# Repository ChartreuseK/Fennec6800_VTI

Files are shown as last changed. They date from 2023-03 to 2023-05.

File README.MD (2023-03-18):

# Fennec 6800 Video Terminal Interface (VTI) Expansion

This expansion board is designed for use with the [Fennec 6800 SBC](https://github.com/ChartreuseK/Fennec6800). It provides a 64 column by 16 line video display over composite ("NTSC") video or a CGA compatible monitor. In addition to the video display it also provides for a parallel ASCII keyboard interface on either a DIP14 IDC header, or over a DA-15 connector. Combined with an Option ROM that hooks into the Fennec 6800's BIOS, this provides for a full video terminal interface for the Fennec, negating the need for an external terminal on the first serial port. 

Connection to the Fennec is accomplished by a 1:1 wired 40 pin IDC cable between the two, multiple expansions may be attached to the bus using such a straight through wired cable. A common 40 pin IDE cable with no key plug may be used for this purpose, however an 80 pin IDE cable should never be used as they internally connect many pins to ground.

Through the use of a 6845 VDP, and socketed crystal, the interface can be reprogrammed to a number of different possible graphics modes. With 2kB of VRAM provided by a 6116/4016 SRAM, the interface can support up to 80x25 text mode when combined with an appropriate dot clock and an 8x8 font. Using a larger font ROM than the 2716 is also possible, with up to 32kB of font ROM being possible, allowing for extra tall and detailed characters. However due to non-interlaced composite video's vertical line count this will result in significantly less lines displayed. 

The ASCII keyboard interface is provided via a 6820/6821/6521 PIA, giving a full 8-bit ASCII interface with strobe to the keyboard. The second 8-bit port of the PIA is not used and is provided on a pin header for the user to experiment with and control. In addition a small prototyping area is available on the right hand side of the card to be used for such experiments.

Only 5v is provided to the keyboard, so vintage keyboards requiring extra voltages such as -12v will need to be supplied that externally.

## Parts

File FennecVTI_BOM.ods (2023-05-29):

Reference(s) | Qty | Part | Digikey Part # | Alternative Digikey Part # (ICs are HCT instead of LS)
C1 | 1 | 470uF 16v Electrolytic 3.5mm pitch 8mm diameter | P19636CT-ND | 493-14210-1-ND
C2 | 1 | 47uF 16v Electrolytic 2mm pitch 5mm diameter | P11196-ND | 493-1775-ND
C3, C4, C5, C6, C7, C8, C9, C10, C11, C12, C13, C14, C15, C16, C17, C18, C19 | 17 | 0.1uF 50v Ceramic Capacitor, .1” pin pitch | 399-14036-1-ND
D1 | 1 | T1-3/4 (5mm) low-brightness red LED | 160-1707-ND
D2 | 1 | 1N4148 DO-3 diode | 1N4148FS-ND
J1 | 1 | 2x20 0.1” male pin header | 10129381-940002BLF-ND | S2011EC-40-ND
J2 | 1 | 2x6 0.1” male pin header | 2057-PH2-12-UA-ND | S2011EC-40-ND
J3 | 1 | Right-Angle RCA connector | 2092-KLPX-0848A-2-Y-ND | PJRAN1X1U04X-ND
J4 | 1 | DE9 Right-Angle Female | AE10921-ND
J5 | 1 | DA15 Right-Angle Female | AE10976-ND
J7 | 1 | 1x14 0.1” male pin header | 2057-PH1-14-UA-ND | S1011EC-40-ND
JP1 | 1 | 1x2 0.1” male pin header | 2057-PH1-02-UA-ND | S1011EC-40-ND
JP2 | 1 | 1x3 0.1” male pin header | 2057-PH1-03-UA-ND | S1011EC-40-ND
JP3 | 1 | 1x2 0.1” male pin header | 2057-PH1-02-UA-ND | S1011EC-40-ND
JP4 | 1 | 1x2 0.1” male pin header | 2057-PH1-02-UA-ND | S1011EC-40-ND
Q1 | 1 | 2N3906-AP TO-92 package PNP | 2N3906FS-ND
R1 | 1 | 4.7k ohm 1/4 5% Carbon Film Resistor | CF14JT4K70CT-ND
R2, R4 | 2 | 220 ohm 1/4 5% Carbon Film Resistor | CF14JT220RCT-ND
R3 | 1 | 10k ohm 1/4 5% Carbon Film Resistor | CF14JT10K0CT-ND
R5 | 1 | 470 ohm 1/4 5% Carbon Film Resistor | CF14JT470RCT-ND
U1 | 1 | 74LS191 DIP | 296-14886-5-ND | 296-2141-5-ND
U2 | 1 | MC6845 | Vintage, eBay
U3 | 1 | 74LS86 DIP | 296-1669-5-ND | 296-2133-5-ND
U4 | 1 | 74LS30 DIP | 296-3693-5-ND | 296-2111-5-ND
U5 | 1 | 6116 SRAM | Vintage, eBay
U6 | 1 | 74LS245 DIP | 296-1655-5-ND | 296-2105-5-ND
U7, U12 | 2 | 2716 EPROM or 28C16 EEPROM | Vintage, eBay
U8 | 1 | 74LS74 DIP | 296-1668-5-ND | 296-1605-5-ND
U9 | 1 | 74LS139 DIP | 296-1640-5-ND | 296-8390-5-ND
U10 | 1 | 74LS574 DIP | 296-1504-5-ND | 296-2129-5-ND
U11, U13, U15 | 3 | 74LS157 | 296-1645-5-ND | 296-2095-5-ND
U14 | 1 | 74LS166 | 296-3662-5-ND | 296-2099-5-ND
U16 | 1 | MC6820/6821 or MOS 6520/6521/65C21 | Vintage, eBay | (Mouser) 955-W65C21S6TPG-14
U70, U120 | 2 | Optional 2764/27128/27256/27512/28C64 subs. For U7/12 | Vintage, eBay | AT28C64B-15PU-ND
X1 | 1 | ACO-12MHz full-can oscillator | 535-9205-5-ND | 535-9169-5-ND
Sockets
U3, U4, U8, J6 | 4 | DIP-14 (0.3”) socket | 2057-ICS-314-T-ND
U1, U9, U14, U11, U13, U15 | 6 | DIP-16 (0.3”) socket | AE9992-ND
U6, U10 | 2 | DIP-20 (0.3”) socket | AE9998-ND
U2, U16 | 2 | DIP-40 (0.6”) socket | ED3033-ND
U5, U7, U12 | 3 | DIP-24 (0.6”) socket | 1175-2554-ND
U70, U120 | 2 | DIP-28 (0.6”) socket substitute for U7,U12 | 2057-ICS-628-T-ND
X1 Socket | 1 | DIP-14 (0.3”) crystal socket. 4 pins fitted | ED90428-ND

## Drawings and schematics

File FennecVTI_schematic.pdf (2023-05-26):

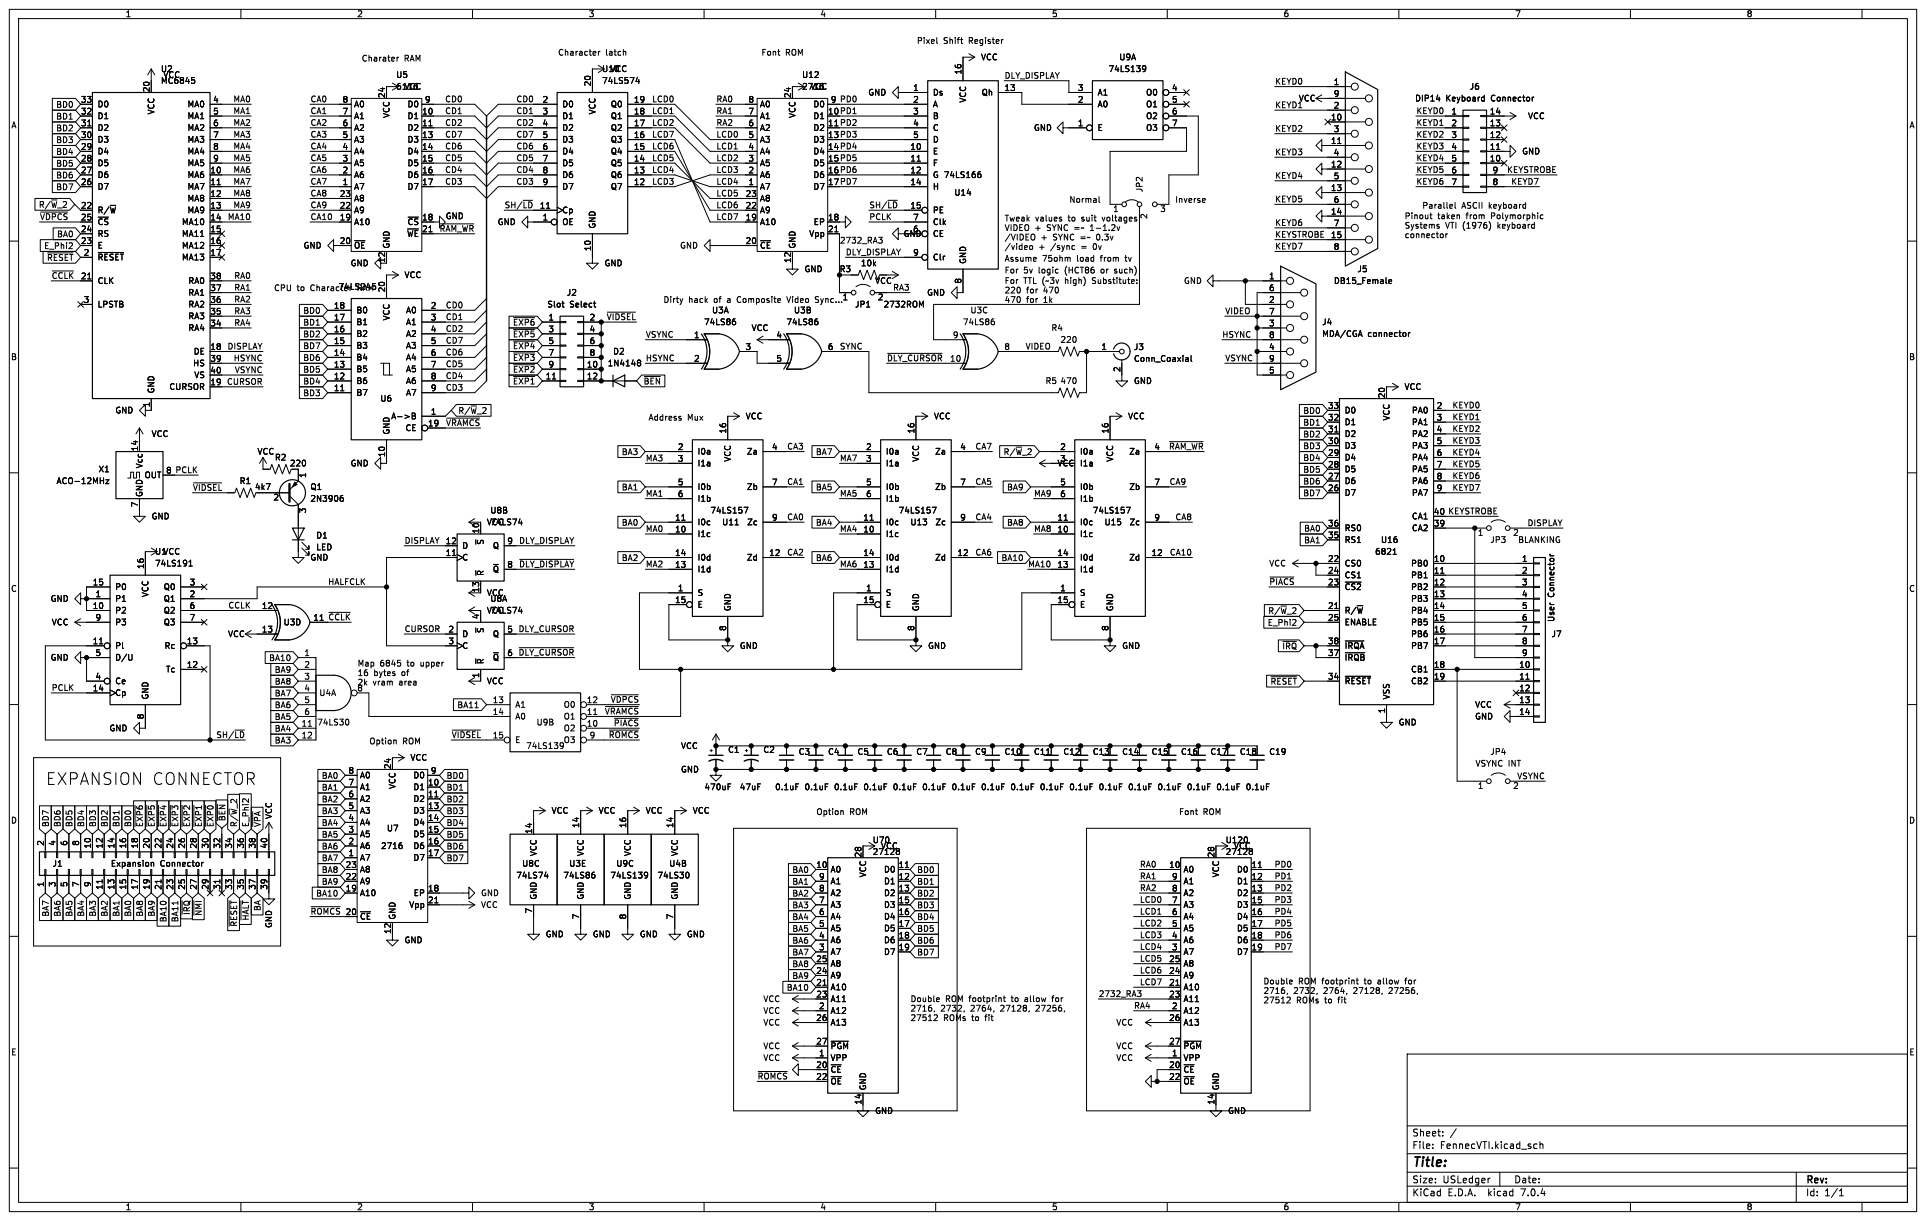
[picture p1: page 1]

1 MA6 10 MA7 11 MA8 12 MA9 13 MA10 14 MA11 15 MA12 16 MA13 17 DE 18 CURSOR 19 ~{RESET} 2 VCC 20 CLK 21 R/~{W} 22 E

Id: 1/1 Title: File: FennecVTI.kicad_sch Sheet: / VCC 14 GND

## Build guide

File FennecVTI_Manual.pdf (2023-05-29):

# Fennec 6800 Video Terminal Interface

## A Motorola 6845 Based Composite Video and ASCII Keyboard Terminal Interface for the Fennec 6800

## Designed By: Chartreuse

2023

Manual Revision 0.1 – May 2023 | 1 | Fennec 6800 VTI User Manual

Dedicated to the Retro Dreams Discord Server for all the help and discussions over the years.

## Introduction

The Fennec 6800 VTI is a simple composite video based terminal interface with parallel ascii keyboard input for the Fennec 6800 single board computer. Video timing is generated by a Motorola 6845 CRT controller, allowing for flexible timings and customization by the end user. 2kB of display memory is provided as well as a 2kB to 8kB font ROM (2716/2732/2764) allowing for an ASCII text display, and optionally pseudo graphics with an appropriate ROM. Input is handled by a parallel ASCII keyboard connection on either a DA-15 connector or a DIP-14 socket. Eight data inputs and a strobe line from the keyboard are passed to a 6820/6821/6520/6521 PIA chip for handling of the keyboard. An option ROM on the board hooks into the primary monitor ROM and redirects the primary I/O from the first serial port to the VTI interface instead.

## Specifications

- MC6845 CRT Controller (CRTC) for flexible display timing and control
- 2kB of video character memory (6116 SRAM)
- 2-8kB Font ROM allowing for a variety of font heights.
- Option ROM provides a local console for the Fennec, negating need for an external terminal
- DA-15 or DIP-14 parallel ASCII keyboard interface provided through 6820/6821/6520/6521 PIA
- Prototyping area on PCB for simple expansions and projects.
- Second un-used port on PIA broken out to headers for prototyping and interfacing.
- Jumperable inverse video allows for both white on black and black on white.
- RCA composite video output. (“NTSC” timing by default)
- DE-9 TTL Video Output (monochrome CGA by default)
- 12MHz dot clock.
- 64x24 Text Display with default dot clock, controllable with CRTC registers.
- Beautiful blue PCB with exposed traces for a refined look.
- Compact Board design, only 8.6×5.2 inches!

The Fennec VTI provides a flexible platform for text-based video generation on the Fennec as well as other systems with a similar bus interface providing a ~4kB memory window for interfacing. The low 2kB is directly mapped to the video memory, with the upper 16 bytes mapping to the 6845 registers. The upper 2kB is mapped to the option rom, with the upper 16 bytes mapping to the PIA registers.

The parallel ASCII keyboard interface is provided on both a DA-15 interface along with a DIP-14 header. The interface consists of 8 data lines, 1 strobe line, and 5v power and ground. Some vintage keyboards may require different voltages in which case an external adapter will be required. The keyboard interfaces directly to the PIA interface, with the data lines going to the A port, and the strobe line to CA1. Due to the flexibility of the PIA this allows the polarity of the strobe to be configured in software, as well as allowing for interrupt driven capabilities on the input in addition to polling.

The PIA also provides a 14 pin prototyping header with the B data port, as well as CA2, CB1, CB2, 5v and ground. This allows for quick and easy prototyping of small circuits to be controlled directly by the

Manual Revision 0.1 – May 2023 | 2 | Fennec 6800 VTI User Manual

Fennec computer. Coupled with the onboard prototyping area, small circuits may be built up semi-permanently into the computer itself.
Two jumpers are also provided which connect VSYNC and BLANK to CB1 and CA2 respectively, allowing for their status to be either queried by the program, or used as an interrupt source. These signals can be used for either simple timing with the VSYNC pin as a 60/50Hz interrupt source, or for advanced CRTC tricks such as only writing to display memory during BLANK to provide snow free operation.
Manual Revision 0.1 – May 2023 | 3 | Fennec 6800 VTI User Manual

## Design Goals

The VTI was designed to give the Fennec it’s own built in I/O system. I find that a computer doesn’t really feel complete by itself without a way of hooking up a display and keyboard directly to it; more-so in terms of homebrew machines where serial console based systems are a dime-a-dozen. The VTI board is intended to fill this gap by providing both a composite video text terminal as well as a keyboard interface. Part of this goal was also in demystifying the 6845 CRTC for myself and learning to interface one to a microprocessor. The VTI originally started as a breadboard project to just get a video circuit working with an interface to the processor. The Fennec’s simple bus allowed for a quick and easy setup and interfacing for the design.

One consideration when using the 6845 and similar CRTC based circuits is how to handle the situation where both the video circuit and the microprocessor both want to access the display memory. There are many approaches here such as synchronizing the processors clock rate to that of the video circuit to allow for seamless access; accessing the video memory only during blanking intervals where the video circuit is not using/caring about the video on screen; adding wait states to the processor till the video controller is no longer accessing the memory; or the simplest option that the CPU always has priority. The simplest option is what I decided to go with in this case.

Now the upside to this CPU always wins option is simplicity, all we need to control the VRAM access is a set of multiplexer chips and data bus buffers. The multiplexer is on the address lines to the VRAM, and control is simply controlled by the CPU selecting the VRAM memory space. The big downside to this approach is what happens during these conflicts? Well “snow” is what happens. Snow is the term used for the appearance of small glitches on the display when the CPU access the VRAM while the CRTC is also trying to display pixel data. Instead of the intended character data, the video circuit instead picks up the state of the data bus from the CPU and displays that instead. This results in an 8x1 pixel section of the video containing garbage for a single frame for each VRAM access. This type of access was fairly common on some early video cards, most notably the IBM CGA card when in 80 column mode. It is an unwanted side effect, but not terribly distracting when VRAM is only updated periodically. Since the VTI card is intended primarily as a text-terminal, this distraction would be minimal and is made up for in the design simplicity.

One thing that can be done in the future with this simple interface is to convert it to the second type. That is only doing VRAM access during blanking. When I created the PCB version of the VTI I thought to add a jumper to allow for the BLANK signal to be hooked up to the PIA providing the keyboard access. Using this the ROM can be upgraded to wait until BLANK is asserted before doing any VRAM accesses. This would slow down the characters per second that the display is capable of but would completely eliminate all snow from the display with only a software and jumper upgrade.

The keyboard interface was a later addition to the project and not present on the original prototyped breadboard circuit. I decided to go with a parallel ASCII keyboard interface to fit with the late 70s type feel and goal of the Fennec, as such keyboards were ubiquitous in systems of the era. In fact, the pinout used on the DIP-14 keyboard connector is taken from a 1976 Polymorphic Systems VTI card for S100 systems that I have in my collection; the card also being one of my primary inspirations for the project. While a PS/2 keyboard interface would be more convenient for users it broke the immersion of the system too much. To compensate though, and because I do not own any parallel ASCII keyboards

Manual Revision 0.1 – May 2023 | 4 | Fennec 6800 VTI User Manual

personally, I did make a side project PCB based off of https://www.n4vlf.net/ps2.html to convert a PS/2 keyboard to the parallel ASCII required.
For interfacing with the keyboard, while I could simply use an 8-bit latch such as the 74LS574 or a period parallel interface like the 8212. I decided to stick with Motorola parts to fit the design of the system. To this end I selected the 6820/6821 PIA chip. This chip provides for two 8-bit general purpose I/O ports along with 4 additional I/O pins that can be configured to fire interrupts among other uses. With this chip I can simply hook up the 8 data lines from the keyboard to one of the I/O ports, and hook up the strobe into to one of those additional I/O lines. Then the setup can be used in either a polled or interrupt driven mode to get the characters from the keyboard. Another benefit of using PIA chip is the ability of the strobe polarity to be chosen and edited in software to adjust for different keyboards, along with translating key codes if needed.

As the PIA provides for two I/O ports and I did not require the second port for the terminal interface, I brought out the port to a pin header on the PCB, allowing for it to be used by the end-user for interfacing with whatever devices and projects they see fit. As well with the extra space on the board a 0.1” pad per hole prototyping area was also left for this purpose.

While not implemented on the board a feature that I believe I should have added was for jumpers to hook up the high address lines on 2732 and 2764 EPROMS to pins on the PIA instead of to additional row address lines on the CRTC. This would allow for software to change between different fonts or even pseudo-graphics on the font rom for display.

Manual Revision 0.1 – May 2023 | 5 | Fennec 6800 VTI User Manual

## Theory of Operation

Video Display
The heart of the video timing is the Motorola 6845 CRTC. This integrated circuit is by and large a glorified counter chip, capable of counting up characters in the horizontal direction, and characters made up of a number of rows in the vertical direction. With this counting it divides a line into a blanking region, a sync pulse in the middle of that blanking region, and a visible region. Likewise in the vertical direction it has a blanking region, a vertical sync region in the middle of the blanking, and a visible region. With just these attributes we get a vertical sync signal, a horizontal sync signal, and a blanking signal. These alone are enough to get a display to synchronize but we still need more in order to display information on the screen. That’s where the address generator comes into play. For each character cell on the screen the CRTC generates an address for us, starting from the top left of the screen, working it’s way to the right, then going down one cell and continuing. The power of the CRTC here is that it’s able to do these for arbitrary row widths, as opposed to discrete circuits that are typically limited to powers of 2 for simplicity sake. As characters on the display are normally
composed of a number of rows, for example 8, the CRTC repeats the character address for that many rows down the screen. To differentiate the rows and move to different rows of the font the CRTC also provides a row address output. This output simply counts the current scanline within the character row. Now the 6845 CRTC is more powerful than this and offers some additional features, but this is enough to explain the heart and building blocks of our video generation circuit.
We’ll start with the visible portion of the screen. For any given time in the visible area the CRTC is outputting a character address on the MA0-MA13 bus. For the Fennec VTI the display memory is 2kB provided by a 6116 SRAM chip thus we need just 11 address lines MA0 to MA10, the upper 3 address lines are left disconnected. These address lines are connected to the SRAM chip through a multiplexer which we will discuss later, but for now just imagine them directly connected to the SRAM chip.
The Fennec VTI video circuit is designed as character based display dividing the screen up into a region of 64x24 characters, and the CRTC chip is designed especially to make this kind of setup easy. The character addresses will be appropriately repeated on subsequent scan-lines with the row address incremented until the number of rows in a character is reached. What all this means for us is that in the SRAM one byte corresponds uniquely to each character cell on the screen in row-column order. The output of the RAM is then latched into a 74LS574 octal d-flip-flop. This flip flop acts to keep the output stable to the font ROM. While likely strictly not needed it should help to slightly reduce the amount of snow on the screen. From this latch the value is then connected to the A3-A10 address inputs to the 2716 font ROM.
At the font ROM we need to combine the the character value we get from the RAM with the row address from the CRTC to select the line in the font that corresponds to the current line on the display. The VTI is primarily designed for use with an 8x8 font, meaning we need 8 rows or 3 bits to uniquely select a row of the font. This row address on RA0-2 from the CRTC is directly connected to the A0-A2 inputs on the font ROM. With a 2716 EPROM this combination of 8+3 bits fully utilizes the ROM. If a
Manual Revision 0.1 – May 2023 | 6 | Fennec 6800 VTI User Manual

larger ROM such as a 2732 or 2764 are used then more rows can be added to the font. To allow the use of this a jumper is provided to connect RA3 to A11 on a 2732. And if the 2764 footprint is used RA4 will also be connected to A12. Keep in mind that on a standard NTSC television we only have 262 scanlines to work with without going into interlaced mode, with only around 240 visible at most, which will limit the useful font heights without compromising with fewer rows of text.
The output of the font ROM is then latched into a 74LS166 8-bit parallel to serial shift register. This shift register is then clocked at the dot clock (12MHz) to output the pixel data serially to the display. Now the complex part here is latching the pixel data at the right point. If we tried to do it right away as the CRTC changes character address we’d be latching the previous character value’s data from the ROM. This is because every step of the circuit has its own delay. The RAM has an access time on the order of 100ns (though in my build my D4016 SRAM is a fast 50ns model). The ROM has an access time on the order of 150ns for the slowest ROMs. And the latch between them is also clocked at a certain point, but also has a small delay on the order of 10ns or so. Now ~300ns doesn’t sound like a lot of time, but at television frequencies and with a dot clock of 12MHz, that 300ns corresponds to 3.6 pixel times. To account for variance and provide a stable synchronous setup I decided that the latch between the RAM and ROM will latch at the same time as the shift register will latch the output of the font ROM. This setup means that there will be a 1 character delay or pipeline from the address changing and the shift register getting that character data. This delay we will account for in the software timing and adjusting the blanking interval, but will provide a rock solid setup without having to worry about variable asynchronous delays.
To time this latch we need to go to the dot clock and how the CRTC is clocked. The 6845 CRTC does not take a dot clock as input but takes in a character clock; remember the CRTC is a character display device. Since our characters are 8 pixels wide (corresponding conveniently to one byte worth of pixels) we need to divide our dot clock by 8 to get our character clock. A 74LS191 4-bit universal bi-directional pre-loadable counter is used for this purpose. To generate the dot clock we make use of the 3

rd bit of the counter to act as a divide by 8 of the dot clock. For timing reasons we will get back to, this character clock is actually inverted before being input into the CRTC.
The counter is pre-loaded with the value 8 (1000 in binary), and is reset to this value every time it overflows. We do this as we only want to use the low 3 bits of the counter, but we also want to make use of the single clock pulse long carry output that the counter provides. This output is normally used for creating a ripple-carry system of multiple counter chips, but we wish to use it to act as our latch signal for the flip flop and shift register. This output is also hooked back up to the parallel load input which will reset the counter to 8 on the next clock cycle, effectively turning the counter into a 3-bit counter. The output is active low and in the schematic is called the SH/LD signal. When high the shift register will be shifting out the data currently in it to the display, and for the single dot clock that it is low the shift register will latch in the new data from the font ROM.
...To be completed...
Manual Revision 0.1 – May 2023 | 7 | Fennec 6800 VTI User Manual

## Assembly

Assembly is rather straight forward but should be accompanied by the schematic or bill of materials to know where to place the various resistors. I’ve corrected this for my future boards, but this board only has the reference designators and not the component values marked.
Like other throughole kits I would recommend starting from the shortest components to the tallest components, and I would personally recommend sockets for the ICs, especially the vintage ones, though they are not required. My personal assembly order would be to do the IC sockets first, even if they’re taller than the resistors, but either approach has it’s merits. For the tantalum capacitors to the side of the RAM, and the two electrolytic capacitors, make sure to get their polarity correct. Both have their positive side marked on the board, for tantalum capacitors their positive lead is normally marked with a + sign or stripe on the capacitor, and for electrolytics their negative side is normally marked with a stripe. If cost is a factor, feel free to omit some of the tantalum capacitors as the number is likely overkill as I miscalculated the current dram of the SRAM chips (mainly due to only a single pair being active at any one time).
Manual Revision 0.1 – May 2023 | 8 | Fennec 6800 VTI User Manual

## Assembly

Assembly is rather straight forward but should be accompanied by the schematic or bill of materials to be safe. All component and IC values are marked on the board itself to facilitate painless assembly. For the dual-size ROM sockets align the socket to the appropriate pin 1 mark depending if using a 28 pin socket for 2764 EPROMs or 24 pin socket for 2716 EPROMs. The inner marking is for 24 pin ROMs. If installing a 24 pin ROM into a 28 pin socket, take care to seat it all the way to the right, leaving the 4 extra socket holes on the pin 1 side.
Like other throughole kits I would recommend starting from the shortest components to the tallest components, and I would personally recommend sockets for the ICs, especially the vintage ones, though they are not required. My personal assembly order would be to do the IC sockets first, even if they’re taller than the resistors, but either approach has it’s merits. For the two electrolytic capacitors, make sure to get their polarity correct. Both have their positive side marked on the board; for electrolytics their negative side is normally marked with a stripe.
If you are using a 74LS86 IC then use the resistor values printed in the footprints, 220 and 470 for R4 and R5 respectively. If you are substituting in a 74HCT86 then use the values written above, substituting the 220 resistor for a 470, and the 470 resistor for a 1k.
Unless you’ve modified the software to work in another slot, place a jumper shorting cap on the left-most (pin 1) pair of pins on J2 to select the EXP6 slot for the board.
As well, place a shorting jumper on pins 1-2 (right most) of J2, connecting the side labelled NORM to the center pin. This configuration will give white text on a black background, use the other position for black text on a white background if desired.
Program the Option ROM with the latest version of vtirom.bin This ROM will provide the routines for the display as well as hook into the main ROM to provide the main monitor console over the VTI instead of the first serial port.
Program the Font ROM with an 8x8 bitmap font of your choice, I do not currently provide one but I recommend the IBM CGA font ROM or similar as a good base choice. The font is stored as 1 byte per row, and top to bottom row order for each ASCII character in order, with the high bit of each byte being the left most pixel of the character.

Required Bodges (REV.0 ONLY)
I highly recommend upgrading to a rev 1 board if possible however a rev 0 board can be brought up to a working state with a few bodges. For wiring I recommend 26 or 30 AWG wire wrap wire (0.4 to 0.25mm wire) for doing the neatest bodges. Wire-wrap wire has thin insulation of Kynar (PVDF) or sometimes Teflon (PTFE) and is silver plated copper wire, and is ideal for bodges like these.
Manual Revision 0.1 – May 2023 | 9 | Fennec 6800 VTI User Manual

Inverting 74LS157 Select Line
Due to a mix-up in the wiring the select line for the 74LS157 mutliplexers is the opposite polarity to expected. This is fixed in rev 1, but in rev 0 boards requires the addition of a 74LS04 hex-inverter to the prototyping area. Install a 74LS04 inverter into the bottom left most area of the prototyping area of the card. Hook up VCC to pin 14, and GND to pin 7. Find the trace that runs under all 3 74LS157 multiplexers, and is between the power and ground lines running horizontally. Cut this trace to the right (if looking from the bottom) of all 3 multiplexers. This should be near where the two power traces end. Solder a wire from the right of this cut to pin 1 on the added inverter. And solder a wire from pin 2 of the inverter to anywhere on this trace to the left of the cut.

Inverted 74LS245 R/W Line
We will be using the same 74LS04 inverted added by the bodge above, so complete that first. On the top side of the board locate U6, the 74LS245. Cut the left most trace below in to the right of the ceramic capacitor, this should be the small trace that runs under the ROM below the IC. Flip the board over. Run a wire from pin 1 of the 74LS245 to pin 4 of the added inverter. Run a wire from pin 3 of the inverter to pin 34 of the expansion connector (if looking from the back with the dsub connectors on the right this is the 4th pin in on the top row).

INV Display Mixup
Directly above the 3 pin header for INV and NOR display. Cut the trace going to the left-most (INV) position of the header below the IC. Flip the board over. Solder a short wire between the INV pin and pin 5 of the 74LS139 U9.
Flip the board right side up again. To the right of the NOR text, cut the pair of traces leading downward before the via. This should be approximately level with the R in NOR. Using a pair of short bodge wires, cross these traces from one side to the other. That is, on the left trace, above the cut run a wire to the right trace below the cut, and for the right trace, above the cut run a wire to the left trace below the cut.

Flipped Composite Jack
The composite video RCA jack has been wired with the signal on the outer shell, and ground on the center pin. You can chose to make an adapter cable which flips this, or perform the following bodges to repair it correctly. On the top side of the board, cut the thick ground trace below the RCA jack between the jack and the DE-9 connector. On the top side of the RCA jack cut both of the thick traces leading from the jack below resistor R5. Flip the board over. Run a wire from the large ground trace below the jack to the single pin on the board edge side of the RCA jack. Cut the trace from the pin 1 side of the ceramic capacitor to the left of the RCA jack leading to the two pin side of the RCA jack. Run a wire from the same ground as before to the pin 1 side of that ceramic capacitor. Run another wire from that capacitor up to the ground lead of capacitor C2. Finally run a wire from the two pin side of the RCA jack (tip) to the board edge side of resistor R5 (directly above the RCA jack).
Manual Revision 0.1 – May 2023 | 10 | Fennec 6800 VTI User Manual

Manual Revision 0.1 – May 2023 | 11 | Fennec 6800 VTI User Manual

## Bill of Materials

Ceramic Capacitors
- 17x 0.1uF 50v X7R with 0.1” (2.54mm) lead spacing Aluminum Electrolytic Capacitors
- 1x 470uF 16v with 3.5mm lead spacing, max diameter 10mm.
- 1x 47uF 16v with 2mm lead spacing, 5mm diameter Sockets (Optional)
- 4x DIP-14
- 6x DIP -16
- 1x DIP-14 *or* DIP-8 crystal socket (only 4 corner pins fitted) for main oscillator
- 2x DIP-20 (0.3” wide)
- 1x DIP-24 (0.6” wide) socket for 6116 SRAM
- 2x DIP-24 (0.6” wide) sockets for ROMs if using 2716/2732
- 2x DIP-28 (0.6” wide) sockets for ROMs if using 2764
- 2x DIP-40 (0.6” wide)
Connectors
- D-sub DA-15 Right-Angle Female with 7.70mm pin edge offset, 9.12mm mounting hole offset
- D-sub DE-9 Right-Angle Female with 7.70mm pin edge offset, 9.12mm mounting hole offset
- RCA Female Jack, Right-Angle
- 1x 2x20 0.1” male pin header
- 1x 2x6 0.1” male pin header
- 3x 1x2 0.1” male pin header
- 1x 1x14 0.1” male pin header
- 1x 1x3 0.1” male pin header
- (I recommend getting 1x40 and 2x40 breakaway headers and cutting them down)
- 2x 0.1” shorting jumper (+1 if using 2732 or larger font ROM)
Resistors
- 1x 10k 1/4W Carbon Film
Manual Revision 0.1 – May 2023 | 12 | Fennec 6800 VTI User Manual

- 2x 220 1/4W Carbon Film
- 1x 4.7k 1/4W Carbon Film
- 1x 470 1/4W Carbon Film
- If using a 74HCT86 or similar then add 1x 1k 1/4W Carbon Film, and leave out one of the 220 ohm resistors
Diodes
- 1x 1n4148 or similar small signal high speed diode
- 1x 5mm LED. Colour of your own preferenceor but a deep red low brightness LED recommended.
Transistors
- 1x 2n3906 PNP Transistor in TO-92 package with staggered center pin Integrated Circuits
- 1x Motorola MC6845 CRTC, any speed grade should be fine
- 1x 12MHz DIP-14 (full can) or DIP-8 (half can) oscillator
- 1x Motorola MC6820/6821 or MOS 6520/6521 or compatible PIA
- 2x 2716 EPROM or 28C16 EEPROM or compatible. 2764 may also be used (larger will work but only first 2kB of option ROM and 8kB of font ROM usable)
- 1x 6116 or compatible (eg. D4016) 2k x 8 SRAM
- 1x 74LS86 quad XOR
- 1x 74LS166 8-bit parallel to serial shift register
- 1x 74LS139 dual 2-4 selector
- 1x 74LS245 octal bus transciever
- 1x 74LS574 octal d-flip-flop
- 1x 74LS30 8 input NAND gate
- 3x 74LS157 2:1 multiplexers
- 1x 74LS191 4-bit universal counter
- 1x 74LS74 dual D-flip-flop
Manual Revision 0.1 – May 2023 | 13 | Fennec 6800 VTI User Manual

## BOM Table

Manual Revision 0.1 – May 2023 | 14 | Fennec 6800 VTI User Manual

## IC Layout Diagram

U5 6116

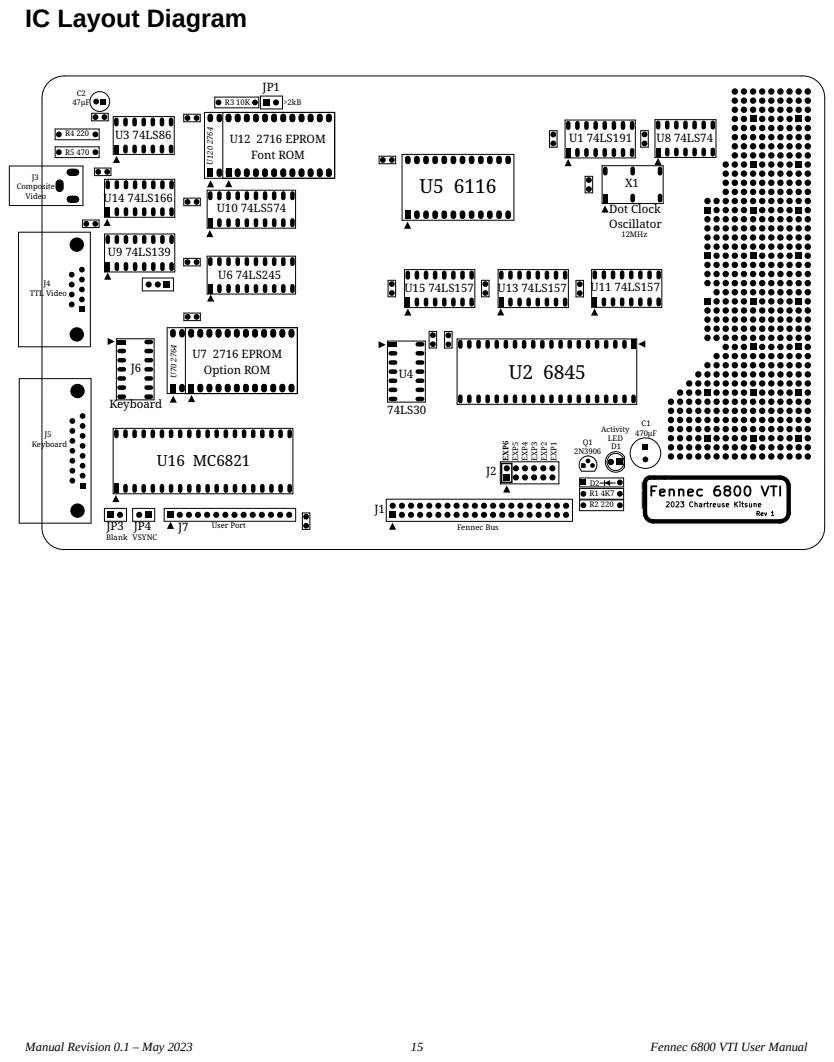
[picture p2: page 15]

## Schematic

For the most up to date schematics, check out the KiCAD project in the repository. These schematics are up to date as of REV 1 or REV 0 with bodges applied.

Manual Revision 0.1 – May 2023 | 16 | Fennec 6800 VTI User Manual

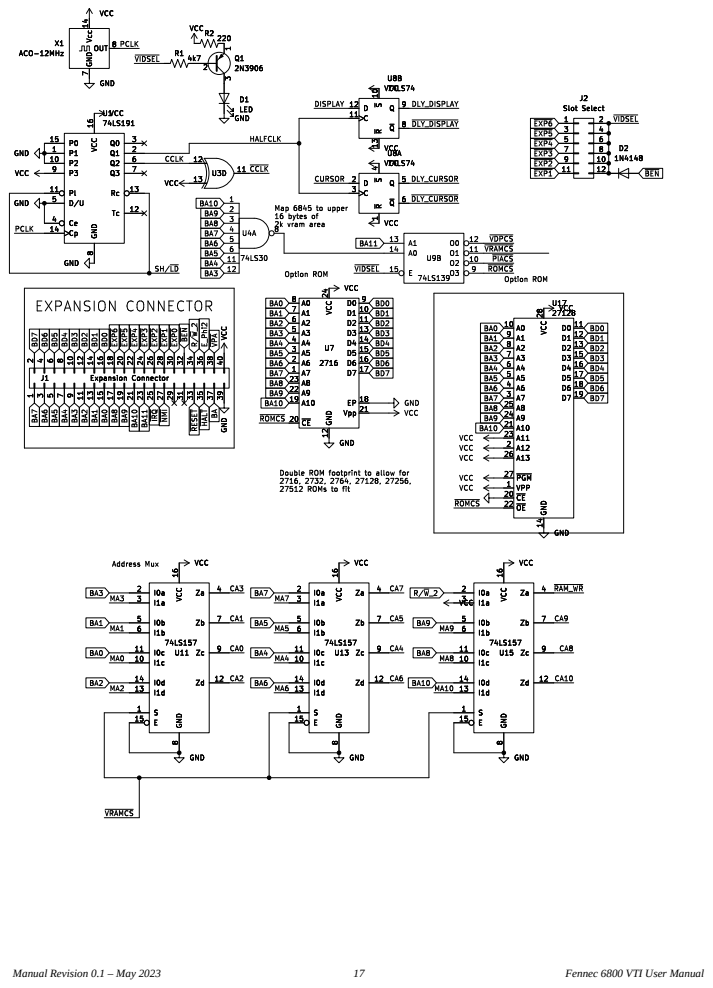
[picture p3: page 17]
Manual Revision 0.1 – May 2023; Fennec 6800 VTI User Manual

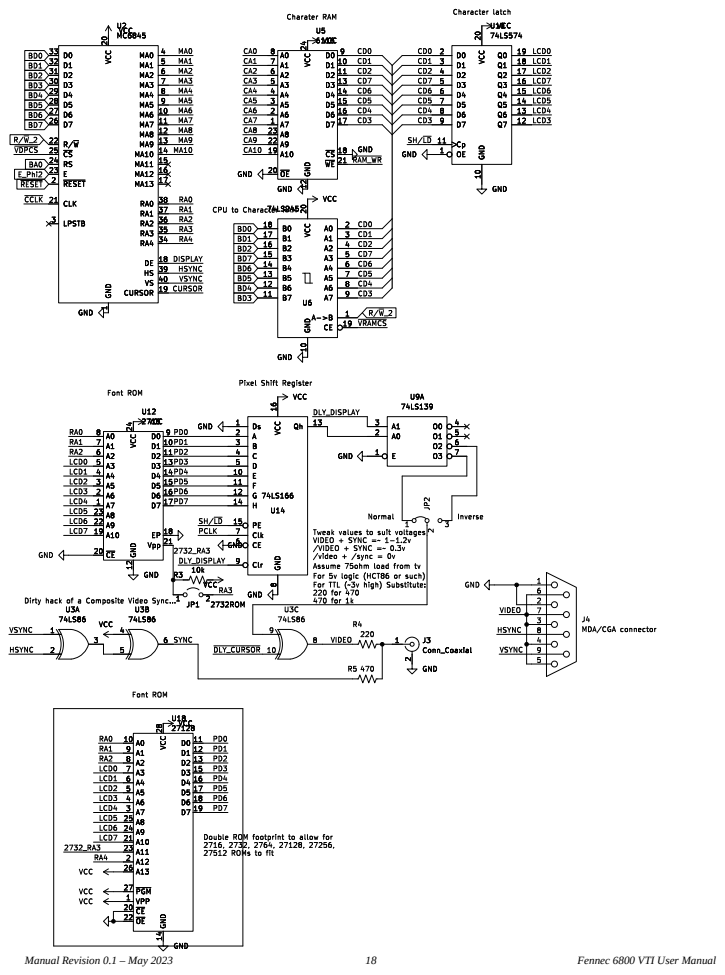
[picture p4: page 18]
Manual Revision 0.1 – May 2023; Fennec 6800 VTI User Manual

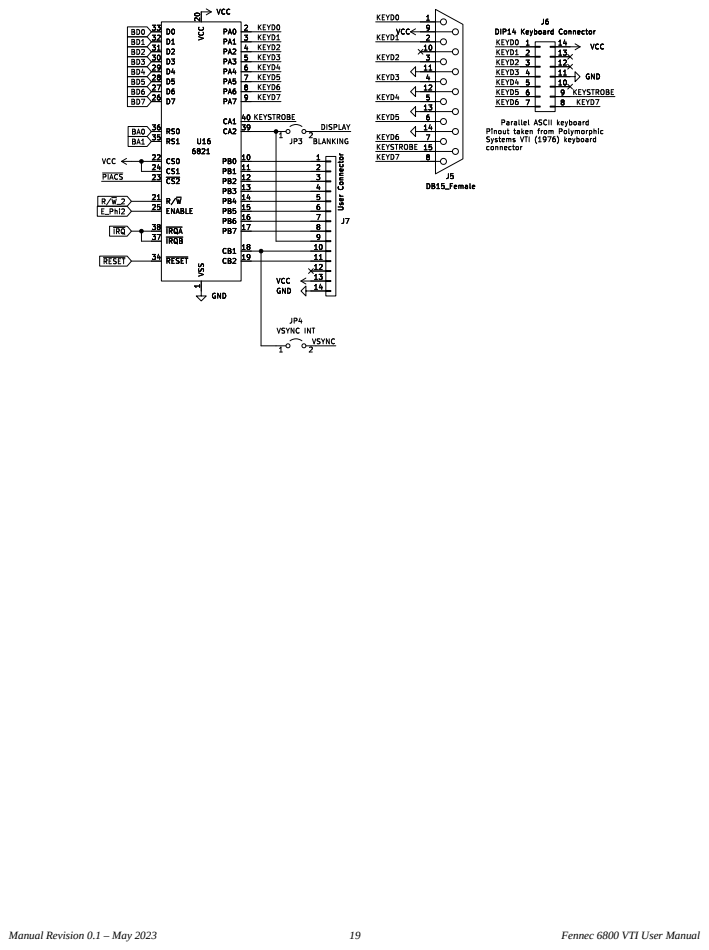
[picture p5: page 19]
Manual Revision 0.1 – May 2023; Fennec 6800 VTI User Manual

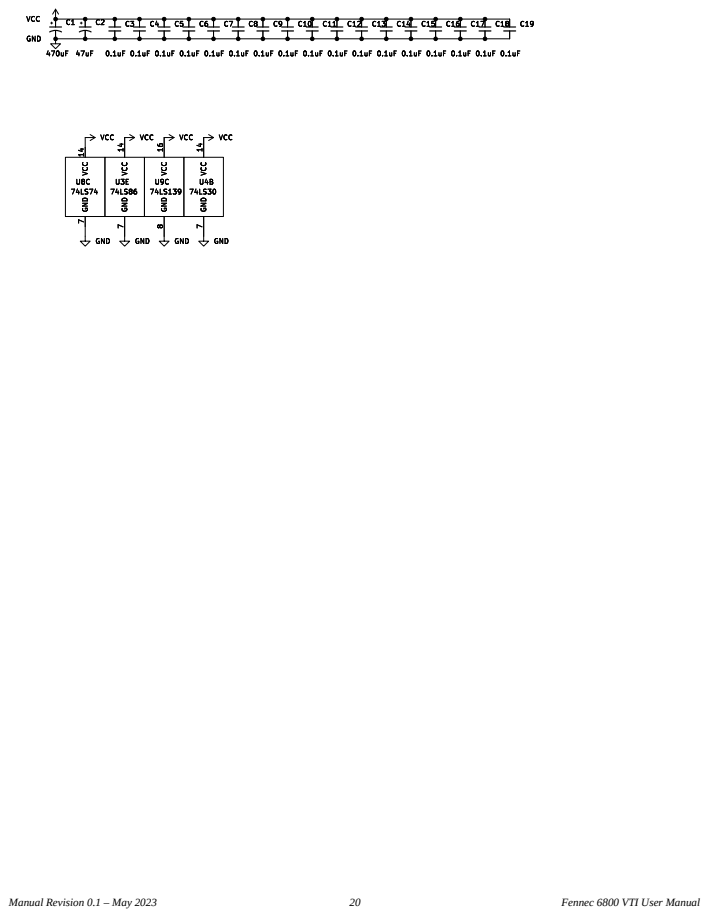
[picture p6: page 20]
Manual Revision 0.1 – May 2023; Fennec 6800 VTI User Manual

Manual Revision 0.1 – May 2023 | 21 | Fennec 6800 VTI User Manual

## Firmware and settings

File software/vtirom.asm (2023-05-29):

; Fennec 6800 VTI - Option ROM v0.1
; Provides a video terminal interface for the Fennec 6800 instead of 
; using a serial terminal hooked up to UART0 on the Fennec.
; Outputs over composite video or TTL video (mono but 15.7kHz)
;
; Input is provided via a parallel ASCII keyboard over a DIP14 socket
; or DA15 port, and processed through a 6820/6821/6520/6521 PIA
; 
; This ROM installs itself as the default console, while swapping
; the default AUX device to UART0 instead of UART1
;-----------------------------------------------------------------------
	CPU 6800
	
VTIBASE EQU $8000	; EXP6 left most jumper
; 9000 for EXP5, A000 for 4, B000 for 3, C000 for 2, D000 for 1

VIDRAM	EQU VTIBASE
ROMBASE EQU VTIBASE+$800	; Upper 2kB of EXP6
; 6845 VDP ports
CRTADDR	EQU VTIBASE+$7F8	; Lowest mirror
CRTDATA	EQU VTIBASE+$7F9
; 6820 PIA ports
PIABASE EQU VTIBASE+$FF8	; Lowest mirror
PIAORA	EQU PIABASE+0		; ORA/INA/DDRA
PIACRA	EQU PIABASE+1
PIAORB	EQU PIABASE+2		; ORB/INB/DDRB
PIACRB	EQU PIABASE+3

; Peripherals on mainboard 
UART1	EQU $EFF0
UART2	EQU $EFF2

; Zero page VTI addresses
VTIVAR	EQU $0040		; Base for our addresses
SAVEX	EQU VTIVAR+0	; w Place to save word
SCRADDR	EQU VTIVAR+2	; w Screen address pointer
SCRX	EQU VTIVAR+4	; b Cursor X pos
SCRY	EQU VTIVAR+5	; b Cursor Y pos

;-----------------------------------------------------------------------
; Controllable routines in ROM
;  - expect no reg preserved, result if any in A
CONTR	EQU $000C	; Start of controllable routines

CONIN	EQU CONTR	; 3 - JMP to GETC routine for console
CONOUT	EQU CONIN+3	; 3 - JMP TO PUTC routine for console
CONINNB	EQU CONOUT+3	; 3 - JMP to GETC (non-blocking) for console

AUXIN	EQU CONINNB+3	; 3 - JMP to GETC routine for aux 
AUXOUT	EQU AUXIN+3	; 3 - JMP TO PUTC routine for aux 
AUXINNB	EQU AUXOUT+3	; 3 - JMP to GETC (non-blocking) for aux

DEVIN	EQU AUXINNB+3	; 3 - JMP to device routine GETC
DEVOUT	EQU DEVIN+3	; 3 - JMP to device routine PUTC
DEVINNB	EQU DEVOUT+3	; 3 - JMP to device routine GETC (non-blocking)
			;  Device routines take device # in B
			;  0 = console, 1 = uart a, 2 = uart b, 
			;  3+ rom or user defined
CONTRE	EQU DEVINNB+3	; End of controllable routines
;-----------------------------------------------------------------------

	ORG ROMBASE
	DW $F10F	; Flo(o)f signature for a bootable ROM
	DB "VTIROM 0.1"	; 10 character name
	DB 0		; Null terminator
	; 3 bytes reserved for future use
	ORG ROMBASE+16	; Entry point at 16 bytes in
START
	JMP ENTER	; Jump over function table
FTABLE	; Table of functions with a static address for user programs
	JMP INITVDP	; Reset VDP
	JMP LOADVDP	; Load VDP registers with custom table
	JMP CLRSCR
	JMP SCROLL
	JMP HOME
	JMP GETC
	JMP GETCNB
	JMP PUTC
	
ENTER
	; We can assume a usable stack from the monitor
	JSR INITVDP		
	JSR INITKBD
	JSR CLRSCR
	JSR HOME
	JSR INSTALL
	RTS		; Return to monitor
	;---------------------------------------------------------------

INITKBD
	LDAA #00	; Select DDR
	STAA PIACRA
	STAA PIAORA	; All 8 pins on A input
	LDAA #07	; Active high strobe,
			; IRQ enabled, 
			; output reg sel
	STAA PIACRA
	LDAA PIAORA	; Read from port to clear flag
	RTS

; Copy VDP register table to VDP
INITVDP
	LDX #CRTTAB
LOADVDP			; (Call here to load with other X)
	CLRB
ILOOP	STAB CRTADDR	; B is current address
	LDAA 0,X	; Value from table
	STAA CRTDATA
	INX
	INCB
	CMPB #16	; 16 registers to fill
	BNE ILOOP
	RTS

; Install handlers into monitor
INSTALL
	;LDX #GETC
	;STX CONIN+1	; +1 to skip over JMP opcode
	LDX #PUTC
	STX CONOUT+1
	;LDX #GETCNB
	;STX CONINNB+1
	RTS

;-----------------------------------------------------------------------
; Get character from console
; TODO change to parallel keyboard
GETC    LDAA #$80	; Check for CA1 interrupt flag
.L	BITA PIACRA	
	BEQ .L		; Wait till we get the strobe
	LDAA PIAORA	; Read in the character and clear flag
	RTS
	
	
; Non-blocking GETC
GETCNB	LDAA #0		; 2 - Default return
	LDAB #$01	; 2 - 
	BITB UART1	; 4 -
	BEQ .E		; 4 -
	LDAA UART1+1	; 4 -
.E	TST A		; 2 - Set flags based on A
	RTS		; 5 -

;-----------------------------------------------------------------------
; Print character in A to the screen (preserve X)
PUTC
	PSHA
	PSHB
	STX SAVEX	; Preserve X register
	LDX SCRADDR	; Get screen pointer (assume up to date)
	CMPA #'\r'	; Carriage return
	BEQ .CR
	CMPA #'\n'	; Newline
	BEQ .NL
	CMPA #'\b'	; Backspace
	BEQ .BS
	CMPA #'\t'	; (Horizontal) Tab
	BEQ .TAB
	; Otherwise assume printable character
	STAA 0,X	; Store to the screen
	INC SCRX	; Move to next character in line
	LDAA SCRX	; Check current X pos
	CMPA #64	; If past screen width?
	BNE .END	
	LDAA #0		; Hit width of screen, go to next line
	STAA SCRX	; Return to 0 	JMP S0OUT
	BRA .NL		; Insert newline
.TAB	LDAA SCRX	; 
	ADDA #8		; Add 8 to force going to next tabstop
	ANDA #$F8	; Round down to the next multiple of 8
	STAA SCRX	
	CMPA #64	; IfJSR GETDISP past screen width?
	BNE .END
	LDAA #0		; Hit width of screen? go to next line
	STAA SCRX	; Return to 0
	BRA .NL		; Newline
.CR	LDAA #0		; Simply return to start of line
	STAA SCRX	; Set X pos to 0
	BRA .END
.NL	INC SCRY	; Try and go to the next line
	LDAA SCRY	
	CMPA #24	; If past screen height?
	BNE .END	
	DEC SCRY	; Return back to last line of screen
	JSR SCROLL	; Scroll the screen up one line
	BRA .END
.BS	LDAA SCRX	; Are we at the start of a line?
	BEQ .END	; If so nothing to backspace
	DEC SCRX	; Otherwise move back one pos
	BRA .END
.END	JSR GETDISP	; Recalculate DISP pointer
	LDX SAVEX	; Restore X
	PULB
	PULA
	RTS

;-----------------------------------------------------------------------
; Scroll screen one line
SCROLL
	LDX #VIDRAM
.LOOP	LDAA 64,X	; Read from next line
	STAA 0,X	; to current line
	INX		; Go from top to bottom till we hit the end
	CPX #VIDRAM+(64*23)	; Start of last line of screen
	BNE .LOOP
	; Now clear last line
	BRA CLREND
;-----------------------------------------------------------------------
; Clear screen (fill with spaces)
CLRSCR
	JSR HOME	; Home cursor
	LDX #VIDRAM
CLREND	; Clear to end of screen starting at X
	LDAA #' '	; Space to clear with
.LOOP	STAA 0,X
	INX
	CPX #VIDRAM+(64*24)
	BNE .LOOP
	RTS
	
;-----------------------------------------------------------------------
; Home cursor (0,0)
HOME
	LDAA #0
	STAA SCRX
	STAA SCRY
	JMP GETDISP

;-----------------------------------------------------------------------
; Convert SCRX, SCRY to screen memory address in SCRADDR
GETDISP
	LDAA SCRY
	RORA		; Low 2 bits to upper 2 bits of addr 
	RORA		; 3x because ROR goes through carry
	RORA
	ANDA #$C0	; Low 2 bits of addr in upper 2
	ORAA SCRX	; Or in x position (6-bits = 64)
	STAA SCRADDR+1	; Low byte of screen address
	LDAB #15	; Cursor position register (low byte) in VDP
	STAB CRTADDR	
	STAA CRTDATA	; Set VDP cursor
	LDAA SCRY	; Now get remaining 3 bits of Y addr
	LSRA		
	LSRA		
	DECB		; high byte cursor position register
	STAB CRTADDR
	STAA CRTDATA	; Set VDP cursor (high)
	ORAA #(VIDRAM>>8)	; VIDRAM base addr
	STAA SCRADDR	; Upper byte of pointer to screen complete
	RTS
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

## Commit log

2023-03-18 Initial commit, rev0 gerbers + partially fixed kicad
    [FennecVTI-B_Cu.gbl, FennecVTI-B_Mask.gbs, FennecVTI-B_Paste.gbp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]
2023-03-18 Changed transistor footprint, removed some 0 length traces
    [FennecVTI.kicad_pcb]
2023-03-18 Added 2764 optional footprint for main rom. Rotated keyboard connector
    [FennecVTI.kicad_pcb, FennecVTI.kicad_sch]
2023-03-18 Tweaked 2764 pinouts, cleanup DRC
    [FennecVTI.kicad_pcb, FennecVTI.kicad_sch]
2023-03-18 Added Teardrops
    [FennecVTI.kicad_pcb]
2023-03-18 Added REV1 gerbers
    [FennecVTI-B_Cu.gbl, FennecVTI-B_Mask.gbs, FennecVTI-B_Paste.gbp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]
2023-05-26 Updated ploted schmeatic
    [FennecVTI.kicad_sch]
2023-05-29 Added BOM
    [FennecVTI_BOM.ods]
2023-05-29 Removed bug corrupting monitor address values. Started keyboard
    [vtirom.asm]
